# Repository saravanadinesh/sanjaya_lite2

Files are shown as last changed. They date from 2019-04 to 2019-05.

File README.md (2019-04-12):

# Sanjaya Lite2
This is the second, improved version of the Sanjaya lite design. Following are the major changes/improvements:
1. The power supply circuitry: Overvoltage protection has been removed, transient protection added, and a large tank capacitor has been added
2. Footprints of slap-on boards adjusted to be more accurate
3. TXB0104 added between ESP32 and SIM800 
4. Transient protection added for RS485

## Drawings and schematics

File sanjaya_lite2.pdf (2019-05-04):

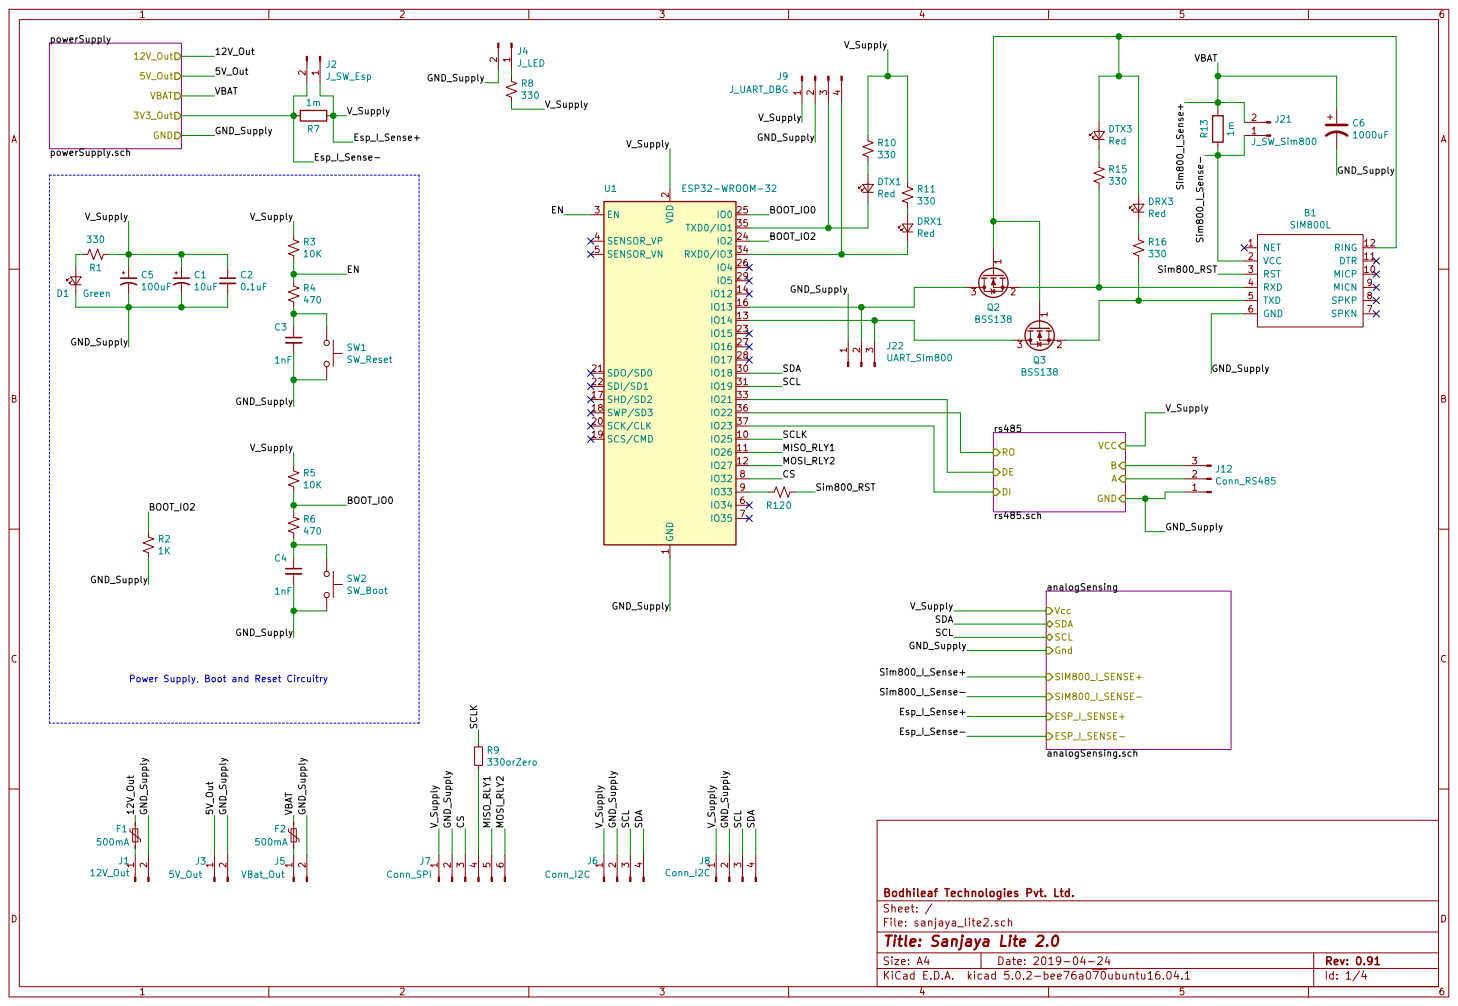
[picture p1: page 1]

2 SCK/CLK 20 SDO/SD0 21 SDI/SD1 22

analogSensing.sch Vcc Gnd SDA

Power Supply, Boot and Reset Circuitry

File: sanjaya_lite2.sch Sheet: / Bodhileaf Technologies Pvt. Ltd.

Id: 1/4 Title: Sanjaya Lite 2.0

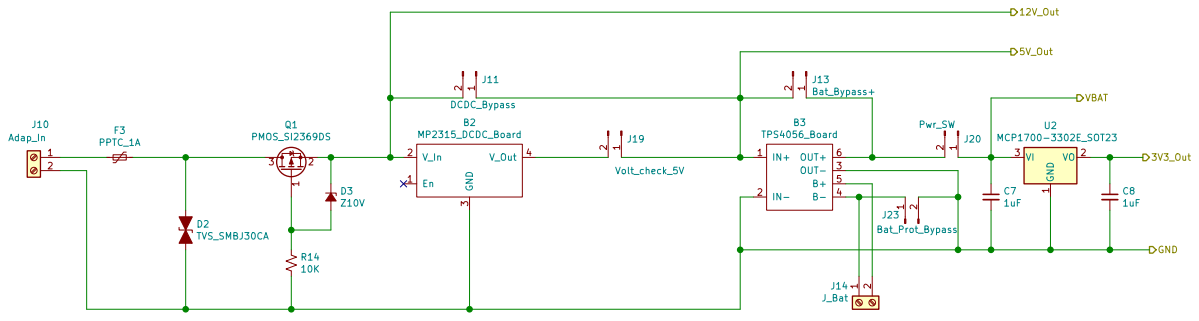
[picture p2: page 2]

Bodhileaf Technologies Pvt. Ltd.
Sheet: /powerSupply/
File: powerSupply.sch
Id: 2/4 Title: Sanjaya Lite 2.0

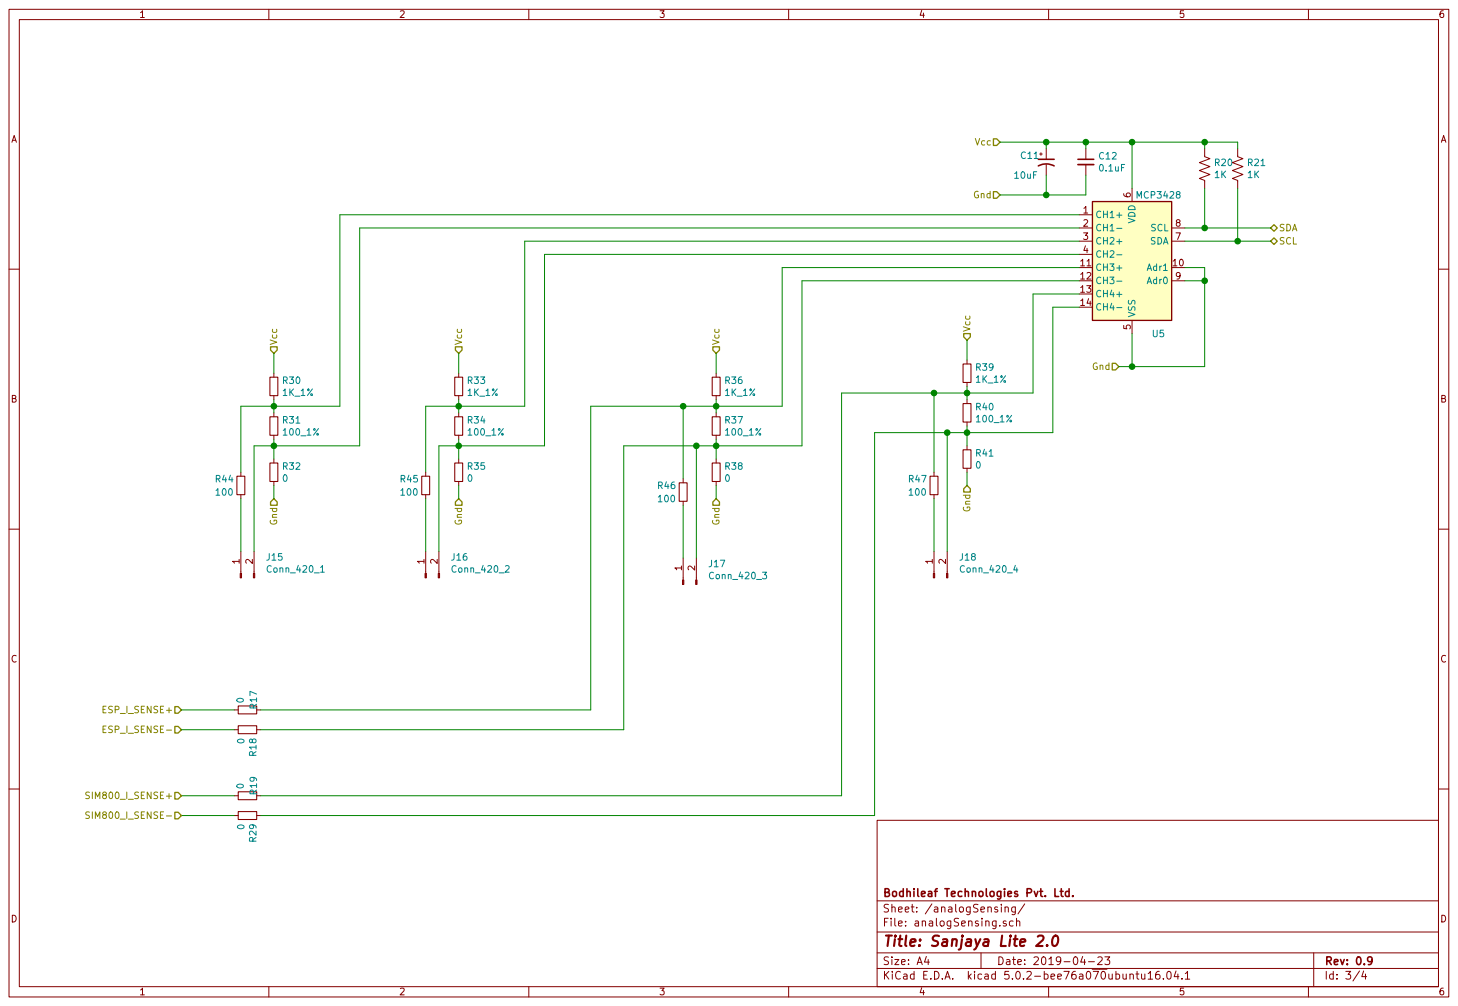
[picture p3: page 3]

6 SDA 7 SCL 8 Adr0 9 U5 MCP3428 Vcc Gnd SDA

Bodhileaf Technologies Pvt. Ltd.
Sheet: /analogSensing/
File: analogSensing.sch
Id: 3/4 Title: Sanjaya Lite 2.0

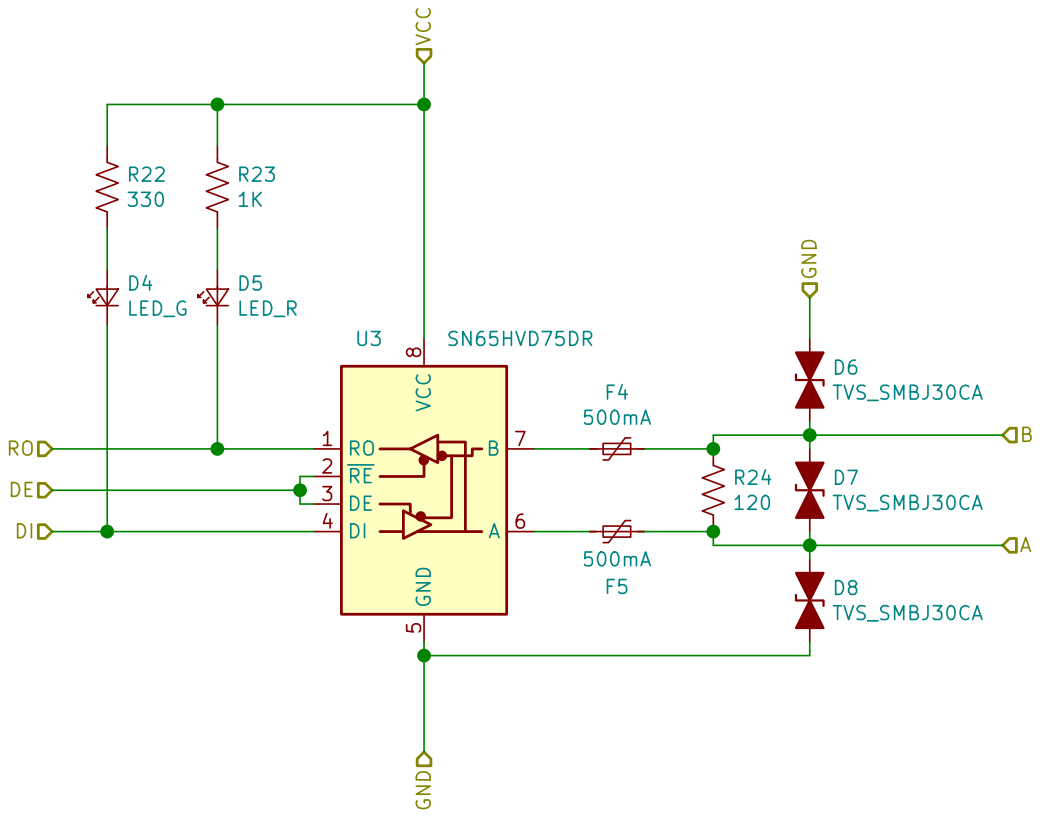
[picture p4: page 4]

File: rs485.sch Sheet: /rs485/ Bodhileaf Technologies Pvt. Ltd.

Id: 4/4 Title: Sanjaya Lite 2.0

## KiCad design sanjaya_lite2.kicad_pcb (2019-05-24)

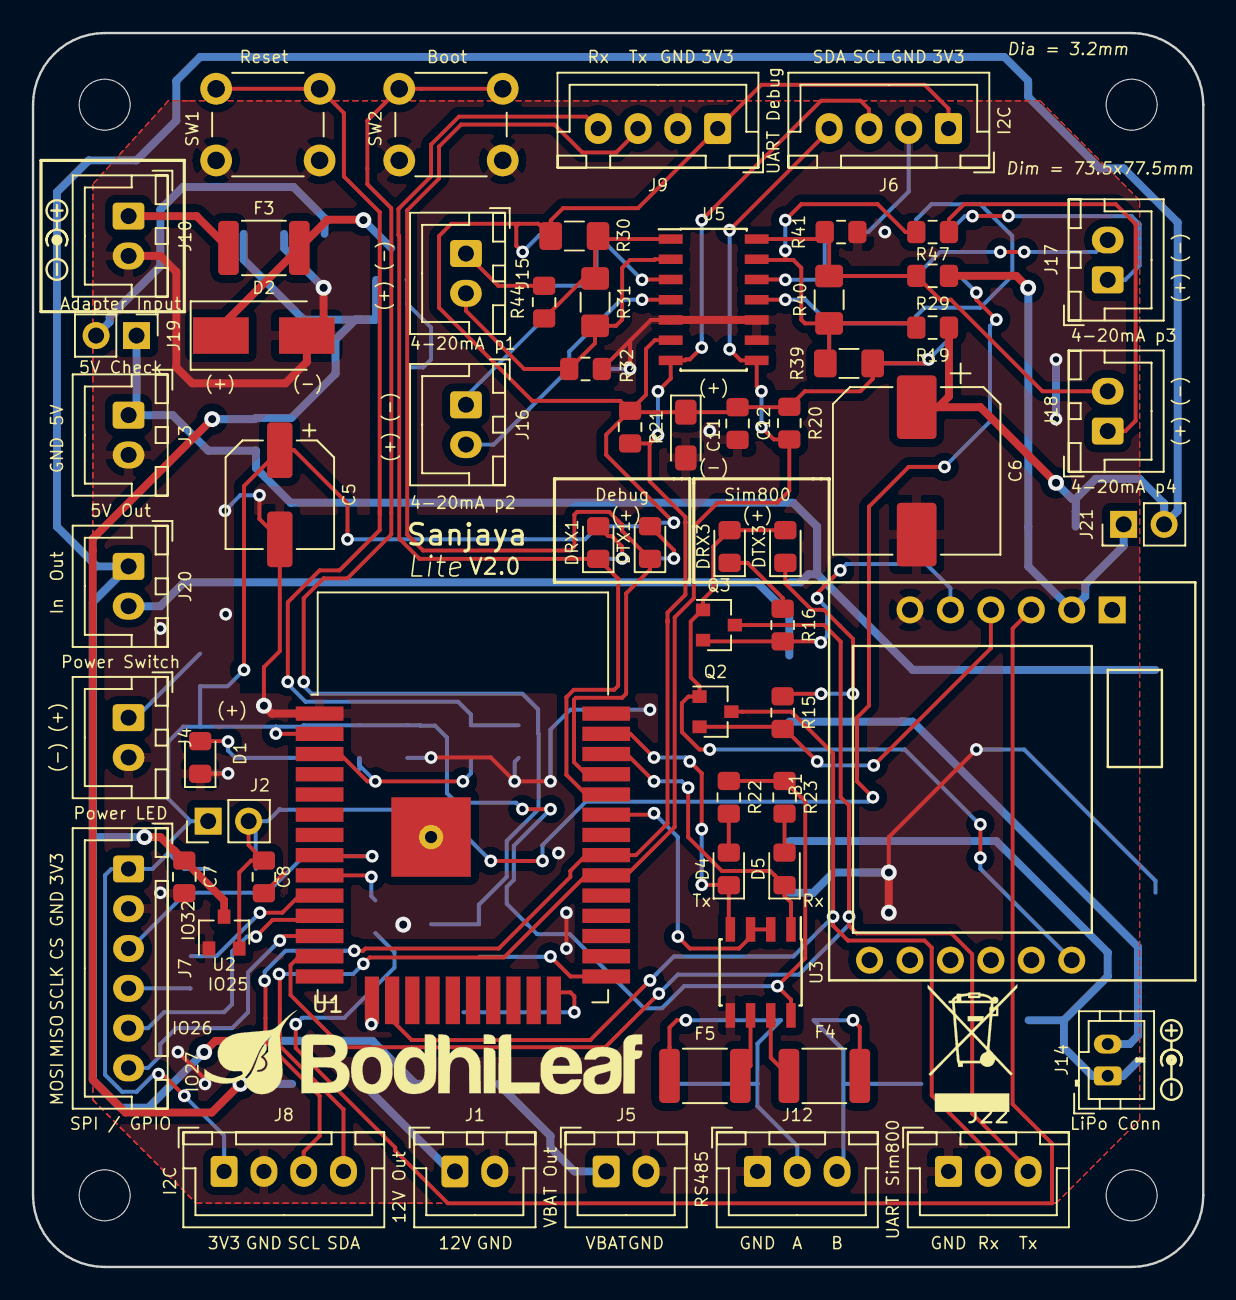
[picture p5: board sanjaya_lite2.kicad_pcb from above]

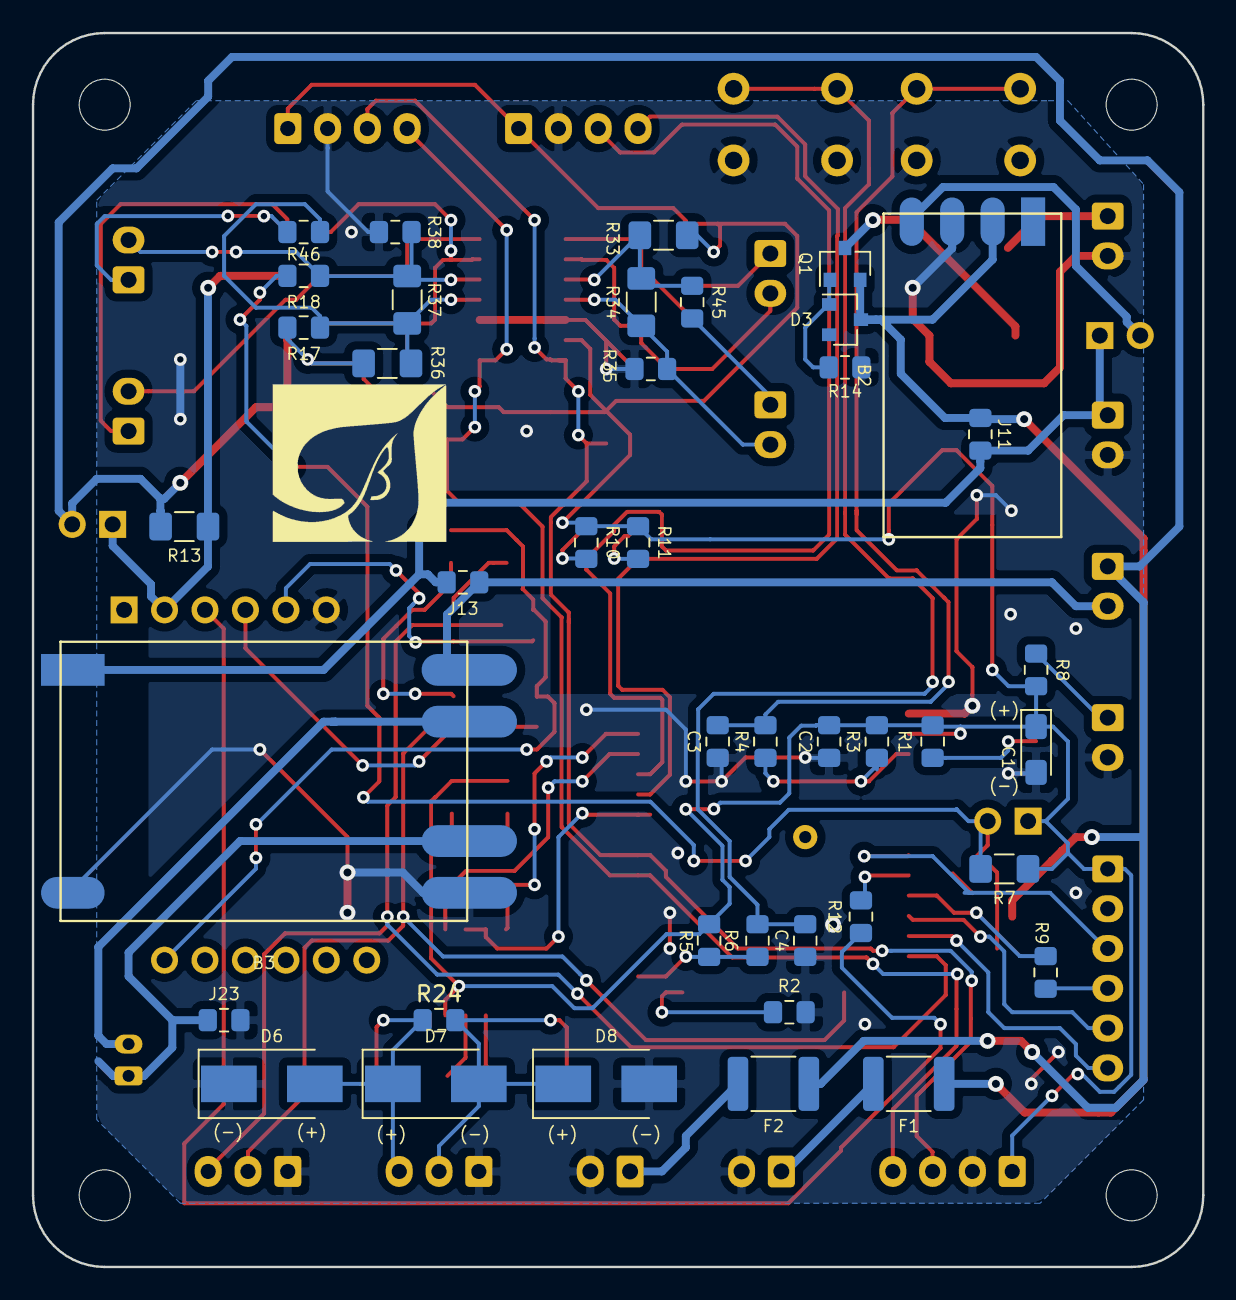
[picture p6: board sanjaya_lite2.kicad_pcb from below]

Board: 2 copper layers, 73.5 x 77.5 mm, 103 parts (41 on the bottom side), 64 nets.

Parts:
B1: SIM800L; Sim800L_Module
B2: MP2315_DCDC_Board; MCP2315_Module
B3: TPS4056_Board; TP4056_Module
C1, C11: 10uF; CP_EIA-3216-10_Kemet-I_Pad1.58x1.35mm_HandSolder
C2, C12: 0.1uF; C_0805_2012Metric_Pad1.15x1.40mm_HandSolder
C3, C4: 1nF; C_0805_2012Metric_Pad1.15x1.40mm_HandSolder
C5: 100uF; CP_Elec_6.3x5.4
C6: 1000uF; CP_Elec_10x10
C7, C8: 1uF; C_0805_2012Metric_Pad1.15x1.40mm_HandSolder
D1: Green; LED_0805_2012Metric_Pad1.15x1.40mm_HandSolder
D2, D6, D7, D8: TVS_SMBJ30CA; D_SMB_Handsoldering
D3: Z10V; D_SOT-23_ANK
D4: LED_G; LED_0805_2012Metric_Pad1.15x1.40mm_HandSolder
D5: LED_R; LED_0805_2012Metric_Pad1.15x1.40mm_HandSolder
DRX1, DRX3: Red; LED_0805_2012Metric_Pad1.15x1.40mm_HandSolder
DTX1, DTX3: Red; LED_0805_2012Metric_Pad1.15x1.40mm_HandSolder
F1, F2, F4, F5: 500mA; Fuse_1812_4532Metric_Pad1.30x3.40mm_HandSolder
F3: PPTC_1A; Fuse_1812_4532Metric_Pad1.30x3.40mm_HandSolder
J1: 12V_Out; JST_XH_B02B-XH-A_1x02_P2.50mm_Vertical
J2: J_SW_Esp; PinHeader_1x02_P2.54mm_Vertical
J3: 5V_Out; JST_XH_B02B-XH-A_1x02_P2.50mm_Vertical
J4: J_LED; JST_XH_B02B-XH-A_1x02_P2.50mm_Vertical
J5: VBat_Out; JST_XH_B02B-XH-A_1x02_P2.50mm_Vertical
J6, J8: Conn_I2C; JST_XH_B04B-XH-A_1x04_P2.50mm_Vertical
J7: Conn_SPI; JST_XH_B06B-XH-A_1x06_P2.50mm_Vertical
J9: J_UART_DBG; JST_XH_B04B-XH-A_1x04_P2.50mm_Vertical
J10: Adap_In; JST_XH_B02B-XH-A_1x02_P2.50mm_Vertical
J11: DCDC_Bypass; R_0805_2012Metric_Pad1.15x1.40mm_HandSolder
J12: Conn_RS485; JST_XH_B03B-XH-A_1x03_P2.50mm_Vertical
J13: Bat_Bypass+; R_0805_2012Metric_Pad1.15x1.40mm_HandSolder
J14: J_Bat; JST_PH_B2B-PH-K_1x02_P2.00mm_Vertical
J15: Conn_420_1; JST_XH_B02B-XH-A_1x02_P2.50mm_Vertical
J16: Conn_420_2; JST_XH_B02B-XH-A_1x02_P2.50mm_Vertical
J17: Conn_420_3; JST_XH_B02B-XH-A_1x02_P2.50mm_Vertical
J18: Conn_420_4; JST_XH_B02B-XH-A_1x02_P2.50mm_Vertical
J19: Volt_check_5V; PinHeader_1x02_P2.54mm_Vertical
J20: Pwr_SW; JST_XH_B02B-XH-A_1x02_P2.50mm_Vertical
J21: J_SW_Sim800; PinHeader_1x02_P2.54mm_Vertical
J22: UART_Sim800; JST_XH_B03B-XH-A_1x03_P2.50mm_Vertical
J23: Bat_Prot_Bypass; R_0805_2012Metric_Pad1.15x1.40mm_HandSolder
Q1: PMOS_SI2369DS; SOT-23
Q2, Q3: BSS138; SOT-23
R1, R8, R10, R11, R15, R16, R22: 330; R_0805_2012Metric_Pad1.15x1.40mm_HandSolder
R2, R20, R21, R23: 1K; R_0805_2012Metric_Pad1.15x1.40mm_HandSolder
R3, R5, R14: 10K; R_0805_2012Metric_Pad1.15x1.40mm_HandSolder
R4, R6: 470; R_0805_2012Metric_Pad1.15x1.40mm_HandSolder
R7, R13: 1m; R_1206_3216Metric_Pad1.42x1.75mm_HandSolder
R9: 330orZero; R_0805_2012Metric_Pad1.15x1.40mm_HandSolder
R12, R17, R18, R19, R29, R32, R35, R38, R41: 0; R_0805_2012Metric_Pad1.15x1.40mm_HandSolder
R24: 120; R_0805_2012Metric_Pad1.15x1.40mm_HandSolder
R30, R33, R36, R39: 1K_1%; R_1206_3216Metric_Pad1.42x1.75mm_HandSolder
R31, R34, R37, R40: 100_1%; R_1206_3216Metric_Pad1.42x1.75mm_HandSolder
R44, R45, R46, R47: 100; R_0805_2012Metric_Pad1.15x1.40mm_HandSolder
SW1: SW_Reset; SW_PUSH_6mm_H4.3mm
SW2: SW_Boot; SW_PUSH_6mm_H4.3mm
U1: ESP32-WROOM-32; ESP32-WROOM-32_Handsolder
U2: MCP1700-3302E_SOT23; SOT-23
U3: SN65HVD75DR; SOIC-8_3.9x4.9mm_P1.27mm
U5: MCP3428; SOIC-14_3.9x8.7mm_P1.27mm

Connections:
/5V_Out: B3.1, J3.1, J11.1, J13.2, J19.1
/12V_Out: B2.2, D3.1, F1.1, J11.2, Q1.2
/BOOT_IO0: R5.2, R6.1, U1.25
/BOOT_IO2: R2.1, U1.24
/CS: J7.3, U1.8
/EN: R3.2, R4.1, U1.3
/Esp_I_Sense+: C1.1, C2.1, C5.1, C11.1, C12.1, J2.1, J6.1, J7.1, J8.1, J9.1, R1.1, R3.1, R5.1, R7.1, R8.2, R10.1, R11.1, R17.2, R20.1, R21.1, R22.1, R23.1, R30.1, R33.1, R36.1, R39.1, U1.2, U3.8, U5.6
/Esp_I_Sense-: C8.1, J2.2, R7.2, R18.2, U2.2
/GND_Supply: B1.6, B2.3, B3.2, B3.3, C1.2, C2.2, C3.2, C4.2, C5.2, C6.2, C7.2, C8.2, C11.2, C12.2, D1.1, D2.2, D6.1, D8.2, J1.2, J3.2, J4.2, J5.2, J6.2, J7.2, J8.2, J9.2, J10.2, J12.1, J22.1, J23.2, R2.2, R14.2, R32.2, R35.2, R38.2, R41.2, SW1.2, SW2.2, U1.1, U1.15, U1.38, U2.1, U3.5, U5.5, U5.9, U5.10
/MISO_RLY1: J7.5, U1.11
/MOSI_RLY2: J7.6, U1.12
/SCL: J6.3, J8.3, R21.2, U1.31, U5.7
/SCLK: R9.1, U1.10
/SDA: J6.4, J8.4, R20.2, U1.30, U5.8
/Sim800_I_Sense+: C6.1, C7.1, F2.1, J20.1, J21.2, R13.2, R19.2, U2.3
/Sim800_I_Sense-: B1.2, J21.1, R13.1, R29.2
/Sim800_RST: B1.3, R12.1
/rs485/A: D7.2, D8.1, F5.1, J12.2, R24.2
/rs485/B: D6.2, D7.1, F4.1, J12.3, R24.1
/rs485/DE: U1.33, U3.2, U3.3
/rs485/DI: D4.1, U1.37, U3.4
/rs485/RO: D5.1, U1.36, U3.1
unnamed: B1.4, Q2.2, R15.2
unnamed: B1.5, Q3.2, R16.2
unnamed: B1.12, DRX3.2, DTX3.2, Q2.1, Q3.1
unnamed: B2.4, J19.2
unnamed: B3.4, J14.1, J23.1
unnamed: B3.5, J14.2
unnamed: B3.6, J13.1, J20.2
unnamed: C3.1, R4.2, SW1.1
unnamed: C4.1, R6.2, SW2.1
unnamed: D1.2, R1.2
unnamed: D2.1, F3.1, Q1.3
unnamed: D3.2, Q1.1, R14.1
unnamed: D4.2, R22.2
unnamed: D5.2, R23.2
unnamed: DRX1.1, J9.4, U1.34
unnamed: DRX1.2, R11.2
unnamed: DRX3.1, R16.1
unnamed: DTX1.1, J9.3, U1.35
unnamed: DTX1.2, R10.2
unnamed: DTX3.1, R15.1
unnamed: F1.2, J1.1
unnamed: F2.2, J5.1
unnamed: F3.2, J10.1
unnamed: F4.2, U3.7
unnamed: F5.2, U3.6
unnamed: J4.1, R8.1
unnamed: J7.4, R9.2
unnamed: J15.1, R44.2
unnamed: J15.2, R31.2, R32.1, U5.2
unnamed: J16.1, R45.2
unnamed: J16.2, R34.2, R35.1, U5.4
unnamed: J17.1, R46.2
unnamed: J17.2, R18.1, R37.2, R38.1, U5.12
unnamed: J18.1, R47.2
unnamed: J18.2, R29.1, R40.2, R41.1, U5.14
unnamed: J22.2, Q2.3, U1.16
unnamed: J22.3, Q3.3, U1.13
unnamed: R12.2, U1.9
unnamed: R17.1, R36.2, R37.1, R46.1, U5.11
unnamed: R19.1, R39.2, R40.1, R47.1, U5.13
unnamed: R30.2, R31.1, R44.1, U5.1
unnamed: R33.2, R34.1, R45.1, U5.3

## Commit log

2019-04-12 Sch files copied from sanjaya_lite project. No mods added yet.
    [analogSensing.sch, powerSupply.sch, sanjaya_lite.sch]
2019-04-13 1. Removed overvoltage protection from power supply, added transient protection, changed LDO 2. Added TXB0104 between ESP32 and Sim800 (partially done)
    [analogSensing.sch, powerSupply.sch, sanjaya_lite2.kicad_pcb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]
2019-04-14 1. Removed TXB0104 and added a simply NMOS based level shifter circuit 2. Added TVS protection for RS485 outputs 3. Changed ADC supply voltage to 3V3. Removed VBAT sensing and instead added current s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
    [analogSensing.sch, powerSupply.sch, rs485.sch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]
2019-04-15 Schematics draft 1 complete
    [analogSensing.sch, powerSupply.sch, rs485.sch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]
2019-04-16 Footprint association done
    [analogSensing.sch, powerSupply.sch, rs485.sch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]
2019-04-16 Minor footprint changes added. Schematic is now layout ready (pending review)
    [analogSensing.sch, powerSupply.sch, rs485.sch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]
2019-04-16 Layout started. Incomplete
    [powerSupply.sch, sanjaya_lite2.kicad_pcb]
2019-04-17 Basic board layout with connectors and large components done
    [powerSupply.sch, sanjaya_lite2.kicad_pcb, sanjaya_lite2.sch]
2019-04-17 Made some changes to the layout. It is still incomplete
    [rs485.sch, sanjaya_lite2.kicad_pcb, sanjaya_lite2.sch]
2019-04-18 Most of the layout done. Some power supply related components are the only ones remaining
    [sanjaya_lite2.kicad_pcb, sanjaya_lite2.sch]
2019-04-18 First layout draft
    [sanjaya_lite2.kicad_pcb, sanjaya_lite2.sch]
2019-04-21 Created a 1A net class
    [sanjaya_lite2.kicad_pcb]
2019-04-21 Some routing done. Minor changes to schematics.
    [powerSupply.sch, rs485.sch, sanjaya_lite2.kicad_pcb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]
2019-04-21 Routing for ESP, Sim800, RS485 done. ADC and terminal routing not yet done.
    [sanjaya_lite2.kicad_pcb]
2019-04-22 Routing other than ground signal completed
    [sanjaya_lite2.kicad_pcb]
2019-04-22 Ground pour on F.Cu and B.Cu added. DRC still not passing. Checking in to save work
    [powerSupply.sch, sanjaya_lite2.kicad_pcb]
2019-04-22 No unconnected tracks. DRC not passing due to one minor issue: ESP pad 39 and solder pad behind it not connected. This is because pad 39 doesn't show up in the schematic and the solder pad behind it 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
    [sanjaya_lite2.kicad_pcb]
2019-04-22 DRC passing after ESP footprint was edited for the thermal pad. Edge cut layer added
    [sanjaya_lite2.kicad_pcb]
2019-04-23 1. Corrected a schematics error where power switch was not cutting power off to VBAT. Made corresponding changes to pcb layout and routing 2. LDO physical location was causing problems with new routi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
    [analogSensing.sch, powerSupply.sch, rs485.sch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]
2019-04-23 Text added. J11 and J13 were found to be underneath dc-dc board footprint. Need to repair it
    [sanjaya_lite2.kicad_pcb]
2019-04-23 Bat_Bypass jumper resistor moved out of DC-DC board's footprint. DC-DC bypass jumper resistor left where it was as it will be soldered only when the DC-DC board isn't present
    [sanjaya_lite2.kicad_pcb]
2019-04-24 Battery JST pin connections swapped. Copper pour restricted near Sim800 antenna area
    [powerSupply.sch, sanjaya_lite2.kicad_pcb, sanjaya_lite2.sch]
2019-05-03 Reversed the battery polarity silk screen symbol as it was wrong. Added polarity indication on F.Silk for D1
    [sanjaya_lite2.kicad_pcb]
2019-05-04 Adding pdf of schematic
2019-05-24 Kicad forced to refill zones. But actually no change from previous commit except new gerber files have been generated
    [sanjaya_lite2.kicad_pcb]
